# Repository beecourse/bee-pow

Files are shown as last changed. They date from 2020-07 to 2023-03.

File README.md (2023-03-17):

bee-pow
=======

The **pow**er supply [bee](https://github.com/beecourse) provides the voltages U_B+ = 15 V, U_B- = - 15 V and U_B2.
The value of U_B2 depends on the jumpers at JP1 and JP2 according to the following table (`--` indicates the jumper position):

  JP1  |  JP2  |          U_B2
-------|-------|------------------------
 `ooo` | `o--` | 5 V generated from U_B2
 `--o` | `--o` | 5 V generated from U3
 `o--` | `ooo` | U3

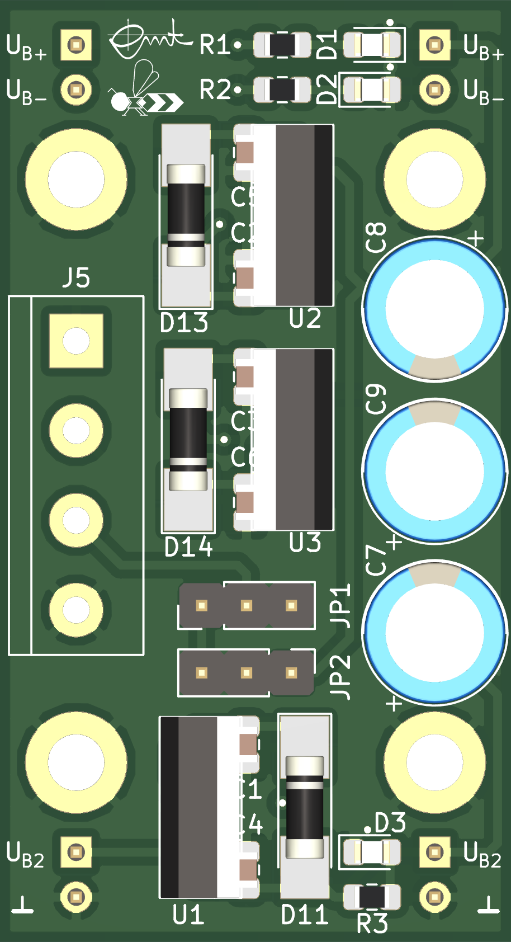
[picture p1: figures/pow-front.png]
Front view of PCB


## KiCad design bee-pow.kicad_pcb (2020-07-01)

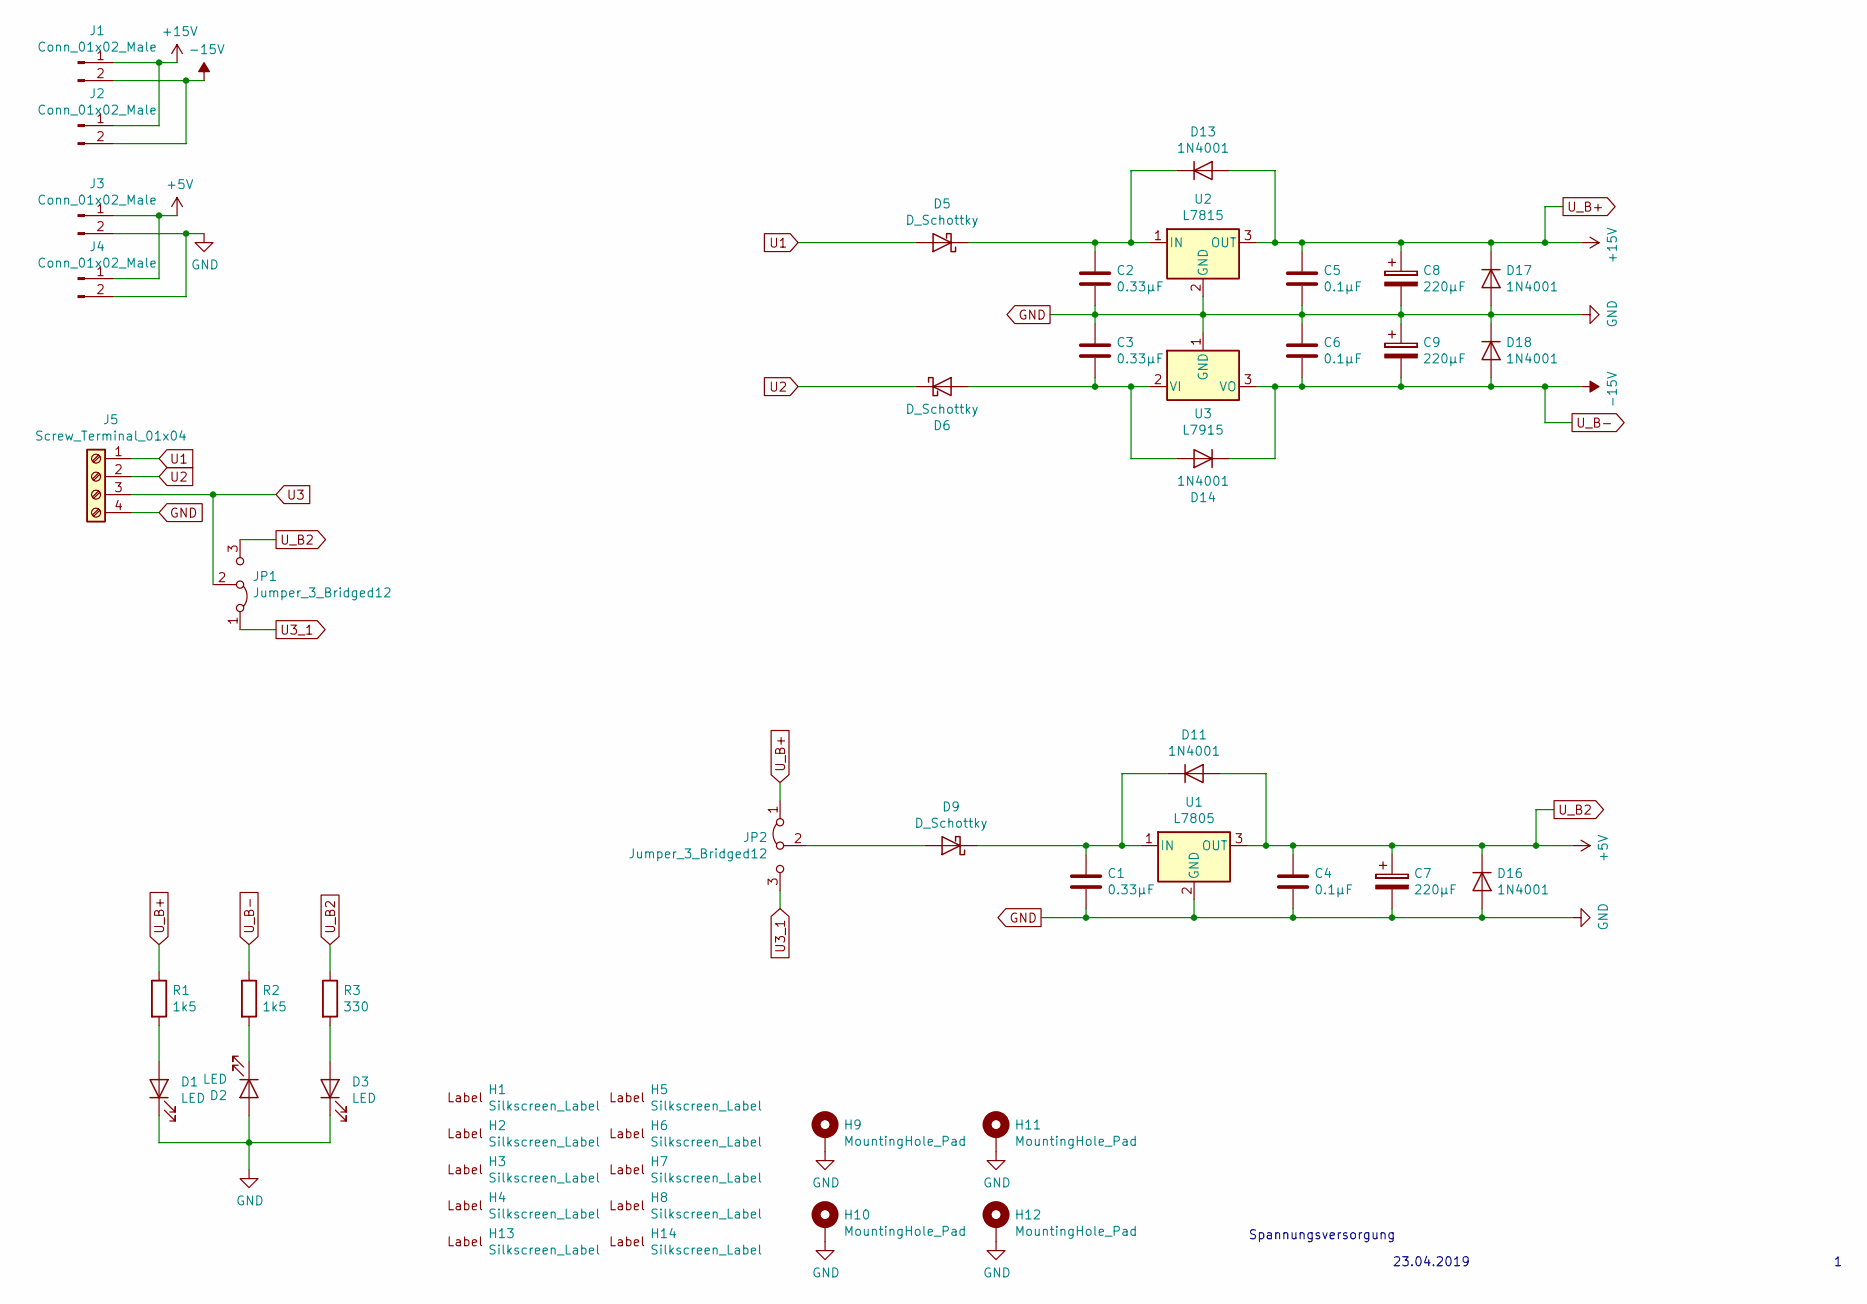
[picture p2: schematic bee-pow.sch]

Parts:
C1, C2, C3: 0.33µF; C_0805_2012Metric_Pad1.15x1.40mm_HandSolder
C4, C5, C6: 0.1µF; C_0805_2012Metric_Pad1.15x1.40mm_HandSolder
C7, C8, C9: 220µF; CP_Radial_D8.0mm_P2.50mm
D1, D2, D3: LED; LED_0805_2012Metric_Pad1.15x1.40mm_HandSolder
D5, D6, D9: D_Schottky; D_SMB
D11, D13, D14, D16, D17, D18: 1N4001; D_MELF_Handsoldering
H1, H2: Silkscreen_Label; Text_U_B+_Silkscreen
H3, H4: Silkscreen_Label; Text_U_B-_Silkscreen
H5, H6: Silkscreen_Label; Text_U_B2_Silkscreen
H7, H8: Silkscreen_Label; Symbol_GND_Silkscreen
H9, H10, H11, H12: MountingHole_Pad; MountingHole_3.2mm_M3_ISO7380_Pad
H13: Silkscreen_Label; EMT-Logo_5.1x2.5mm_Silkscreen
H14: Silkscreen_Label; BEE-Logo_Silkscreen_small
J1, J2, J3, J4: Conn_01x02_Male; PinHeader_1x02_P2.54mm_Vertical
J5: Screw_Terminal_01x04; TerminalBlock_bornier-4_P5.08mm
JP1, JP2: Jumper_3_Bridged12; PinHeader_1x03_P2.54mm_Vertical
R1, R2: 1k5; R_0805_2012Metric_Pad1.15x1.40mm_HandSolder
R3: 330; R_0805_2012Metric_Pad1.15x1.40mm_HandSolder
U1: L7805; TO-220-3_Vertical
U2: L7815; TO-220-3_Vertical
U3: L7915; TO-220-3_Vertical

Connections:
GND: C1.2, C2.2, C3.1, C4.2, C5.2, C6.1, C7.2, C8.2, C9.1, D1.1 (K), D2.2 (A), D3.1 (K), D16.2 (A), D17.2 (A), D18.1 (K), H9.1, H10.1, H11.1, H12.1, J3.2, J4.2, J5.4, U1.2 (GND), U2.2 (GND), U3.1 (GND)
unnamed: C1.1, D9.1 (K), D11.1 (K), U1.1 (IN)
unnamed: C2.1, D5.1 (K), D13.1 (K), U2.1 (IN)
unnamed: C3.2, D6.2 (A), D14.2 (A), U3.2 (VI)
unnamed: D1.2 (A), R1.2
unnamed: D2.1 (K), R2.2
unnamed: D3.2 (A), R3.2
unnamed: D9.2 (A), JP2.2 (C)
U1: D5.2 (A), J5.1
U2: D6.1 (K), J5.2
U3: J5.3, JP1.2 (C)
U3_1: JP1.1 (A), JP2.3 (B)
U_B2: C4.1, C7.1, D11.2 (A), D16.1 (K), J3.1, J4.1, JP1.3 (B), R3.1, U1.3 (OUT)
U_B+: C5.1, C8.1, D13.2 (A), D17.1 (K), J1.1, J2.1, JP2.1 (A), R1.1, U2.3 (OUT)
U_B-: C6.2, C9.2, D14.1 (K), D18.2 (A), J1.2, J2.2, R2.1, U3.3 (VO)

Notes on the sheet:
23.04.2019
Spannungsversorgung

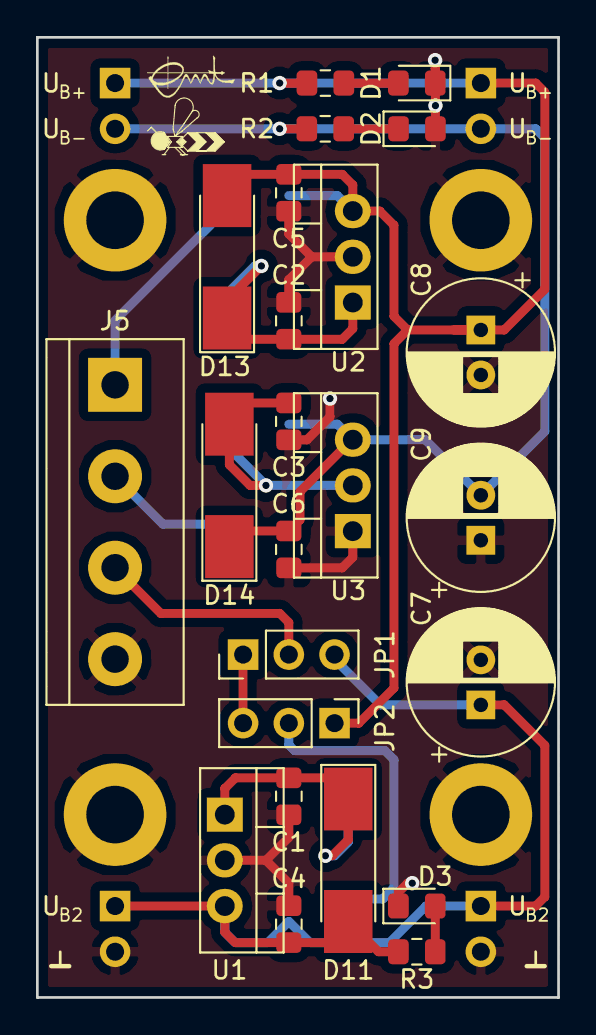
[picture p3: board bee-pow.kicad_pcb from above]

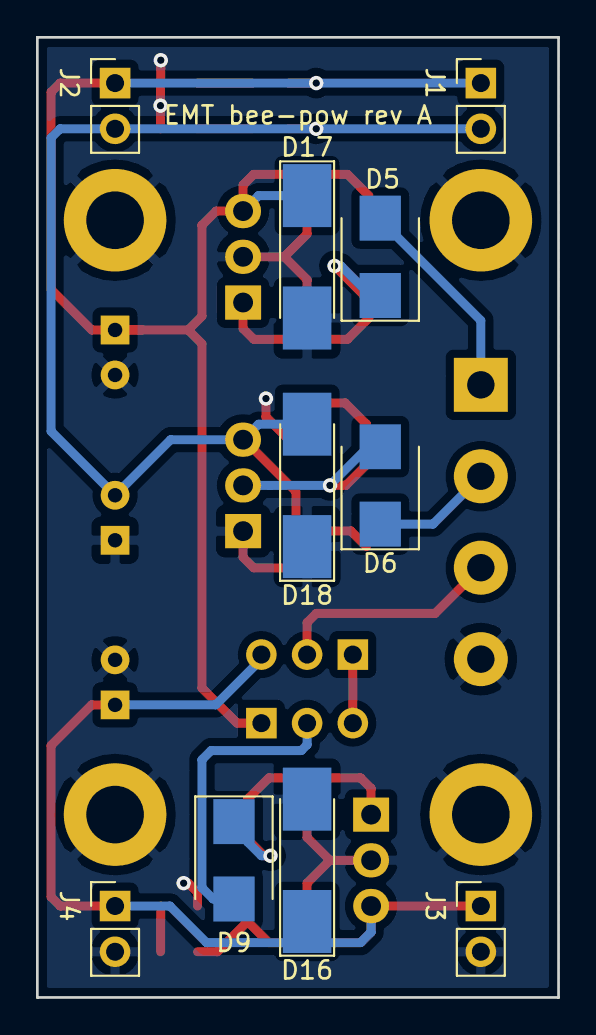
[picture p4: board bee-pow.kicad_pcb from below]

Board: 2 copper layers, 29.0 x 53.3 mm, 48 parts (10 on the bottom side), 15 nets.

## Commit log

2019-04-17 first commit - empty project
    [bee-pow.kicad_pcb, bee-pow.sch]
2019-04-23 begin schematic
    [bee-pow.kicad_pcb, bee-pow.sch]
2019-04-25 schematic and layout
    [bee-pow.kicad_pcb, bee-pow.sch]
2019-04-29 Place refs on bottom silkscreen.
    [bee-pow.kicad_pcb]
2019-04-30 Update labels and mounting holes.
    [bee-pow.kicad_pcb, bee-pow.sch]
2019-05-03 Add ground plane.
    [bee-pow.kicad_pcb]
2019-05-03 Add text and logos.
    [bee-pow.kicad_pcb, bee-pow.sch]
2019-05-03 DRC - add missing via, fix part distances.
    [bee-pow.kicad_pcb]
2019-05-08 Add part numbers.
    [bee-pow.sch]
2019-05-22 Fix LED label position.
    [bee-pow.kicad_pcb]
2020-07-01 Relabel as bee specific.
    [bee-pow.kicad_pcb, bee-pow.sch]
2023-03-17 Add figure showing top view of PCB
